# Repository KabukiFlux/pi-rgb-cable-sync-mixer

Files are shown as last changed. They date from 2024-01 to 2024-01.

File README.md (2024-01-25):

# RGBpi cable sync mixer

Small PCB mod to mix the sync in the RGBpi cable to solve sync issues

## Table of contents

- [Why](#why)
- [Description](#description)
- [Schematics](#schematics)
- [Install](#install)
- [Pics and final result](#pics-and-final-result)

## Why?

In order to eliminate/mitigate the sync issues on the cable we can do several options,
one is to use the common XOR mixer as usual, this other approach reduces the BOM
and enables the PCB to fit in the scart cable connector without any problem.

As you can see on this screenshot the original cable without modding induces a lot of 
DC bias on the sync causing some issues on some TVs, arcade monitors and so: 

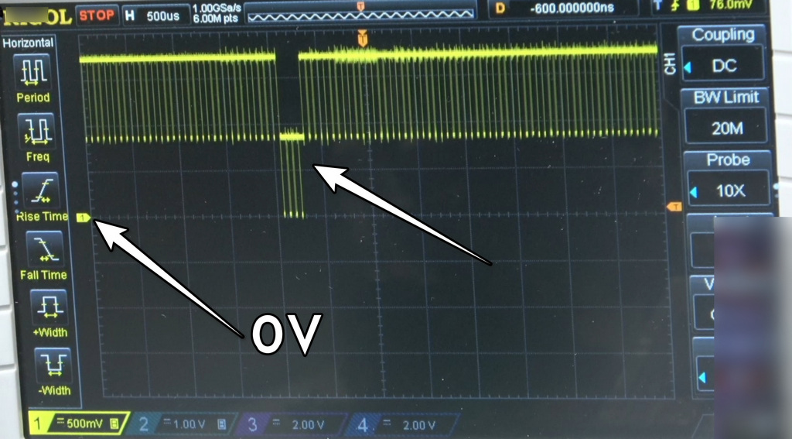
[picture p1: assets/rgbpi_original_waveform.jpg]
RGBpi original cable waveform


With this mod we remove the DC offset not mixing into a full CSync signal but at least
we enable it to be used on more systems, of course the best approach is always the active sync
mixer with some gates but with this mod we restore at least the basic functionality.

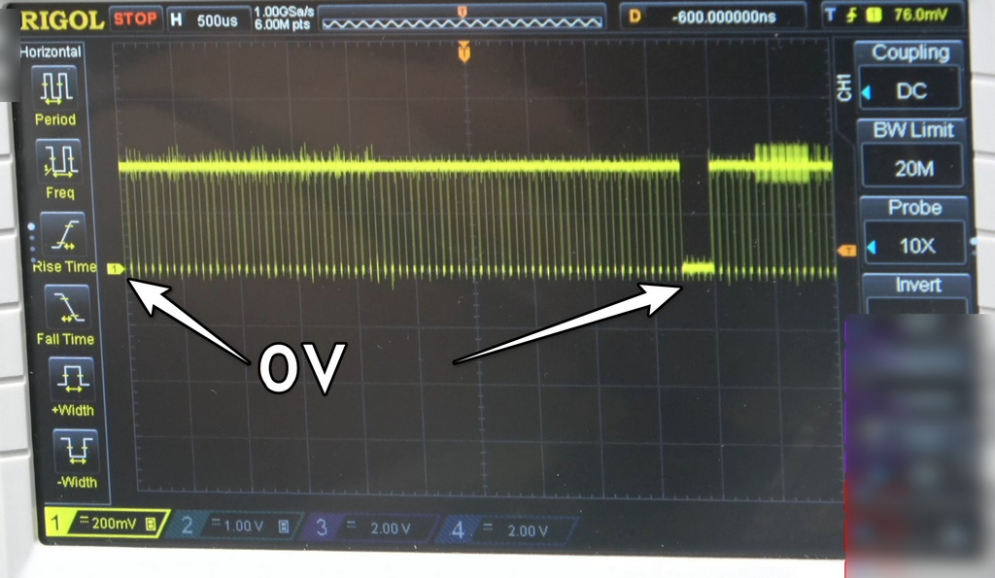
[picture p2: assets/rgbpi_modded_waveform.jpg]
RGBpi modded cable waveform


Yes, the vertical period is not as good as with an active mixer but at least it removes the sync
issues on most devices with a very small BOM.

### OSSC comparison

Without modding:

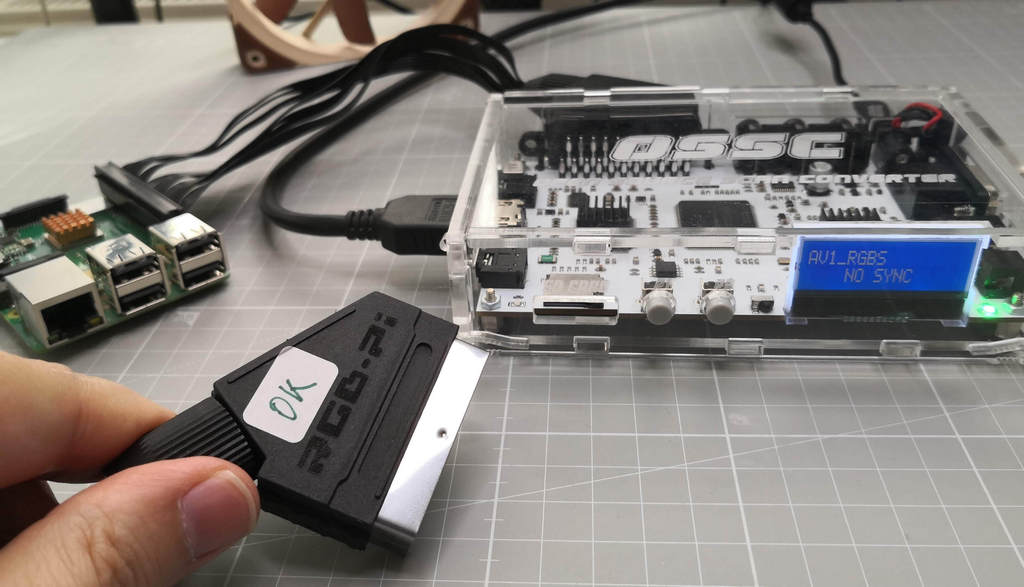
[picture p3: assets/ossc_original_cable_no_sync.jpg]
OSSC without modding


Modded cable:

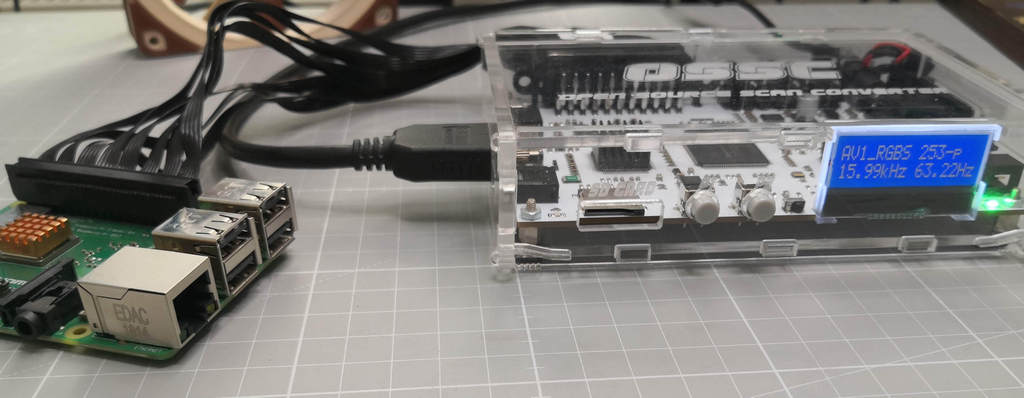
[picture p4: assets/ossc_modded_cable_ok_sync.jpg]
OSSC modded cable


## Description

This is intended to be a very small PCB to be included inside the scart connector on the rgbpi cable.

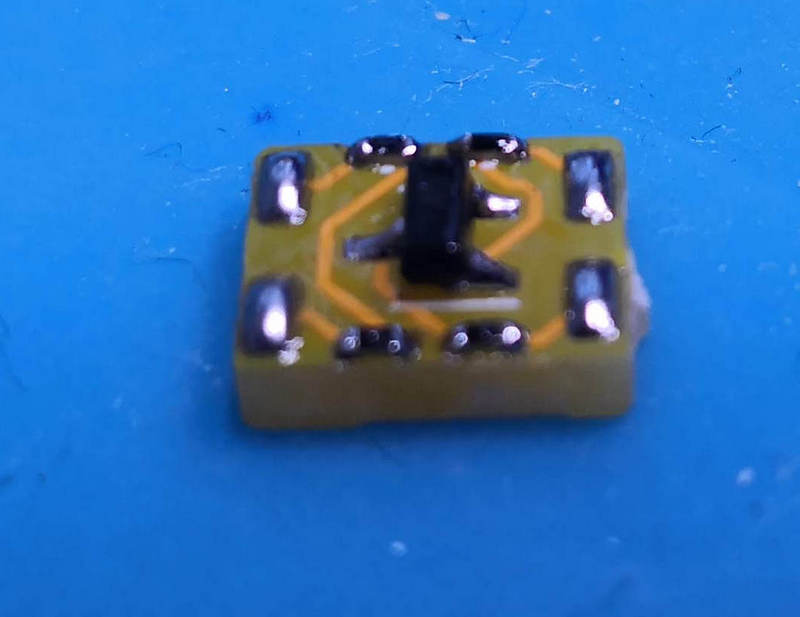
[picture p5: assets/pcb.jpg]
Sync mixer PCB


It is valid for all the rgbpi cable versions, we will see on the installation procedure V1 and V2 cables.

In the BOM directory there's an interactive BOM with all the required components.

In the gerbers directory we have the gerbers to manufacture the boards.

In the KiCAD folder we can find the KiCAD project itself.

## Schematics

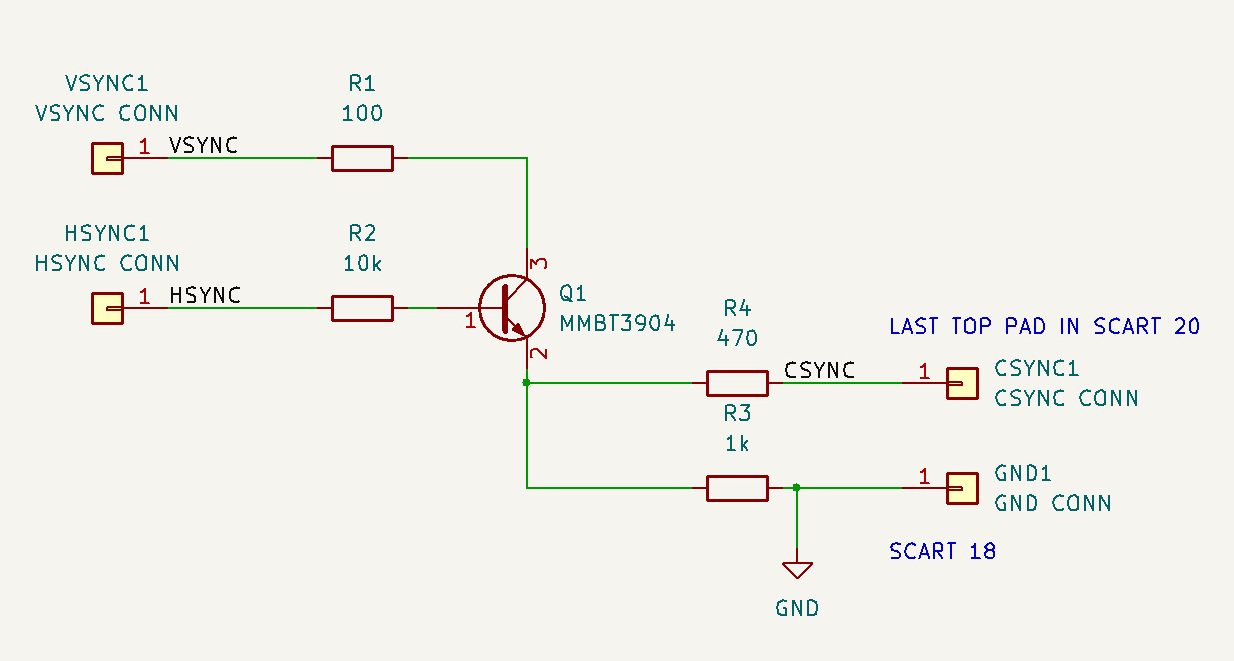
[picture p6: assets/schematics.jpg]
Schematics


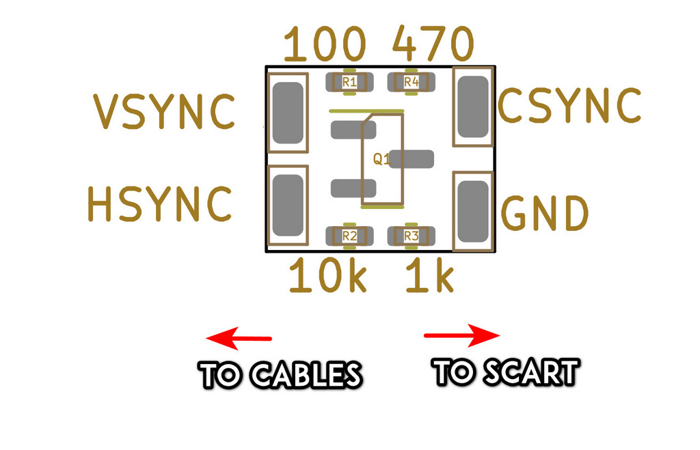
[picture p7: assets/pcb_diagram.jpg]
PCB footprint


You can find here as well as the KiCAD files inside the KiCAD folder.

## Install

1- Send to manufacture the GERBER board to JLCPCB or other PCB manufacturer.

2- Get the components required, you can see here the Bill Of Materials [BOM](bom/ibom.html)

3- Solder the components.

4- Follow the procedure depending on your cable version.

### Detect your cable version

This is what we will call V1, follow the V1 install procedure:

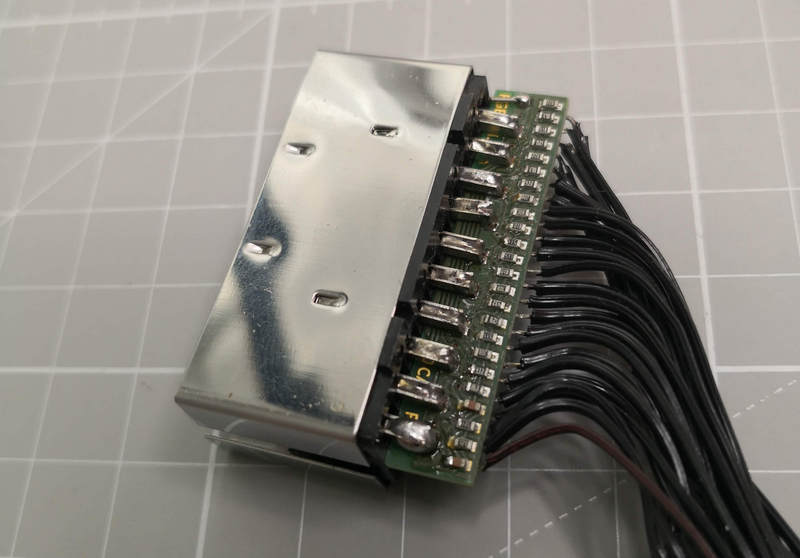
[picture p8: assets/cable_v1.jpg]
Cable V1


This is what we will call V2, follow the V2 install procedure:

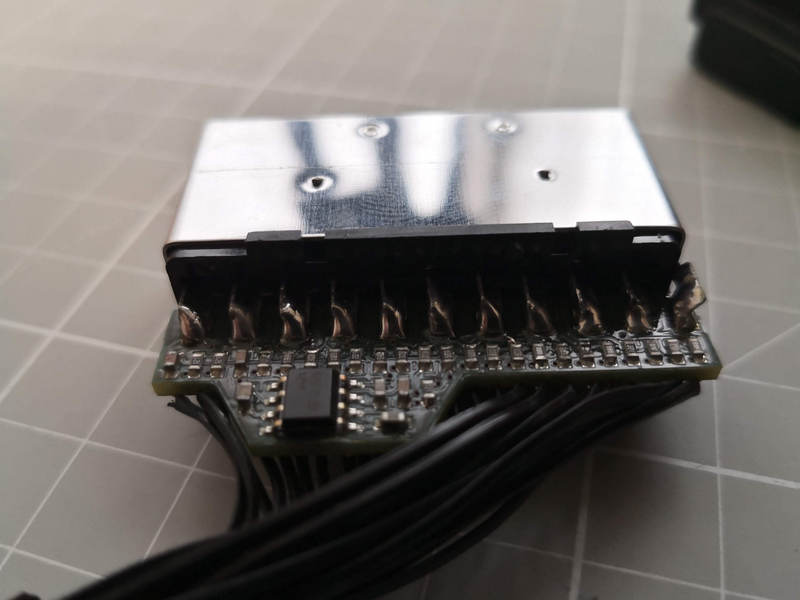
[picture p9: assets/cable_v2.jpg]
Cable V2


### V1 cable install

If your cable is V1 then:

* Check the wires for the installation

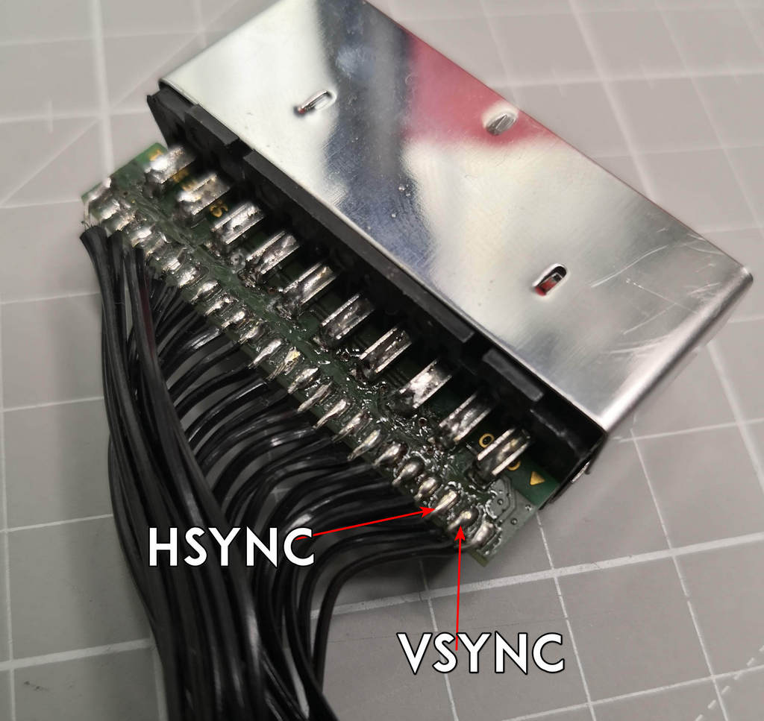
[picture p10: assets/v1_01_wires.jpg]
v1 wires


* Check the soldering positions

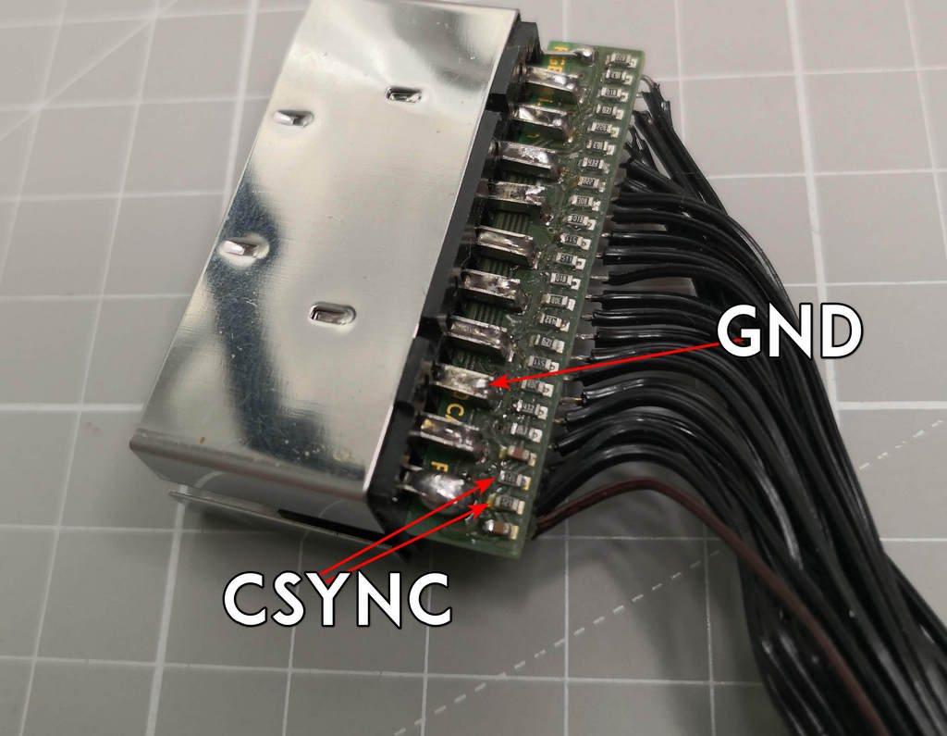
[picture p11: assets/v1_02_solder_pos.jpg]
v1 soldering positions


* Solder as shown (the big white cable is not required by this mod)

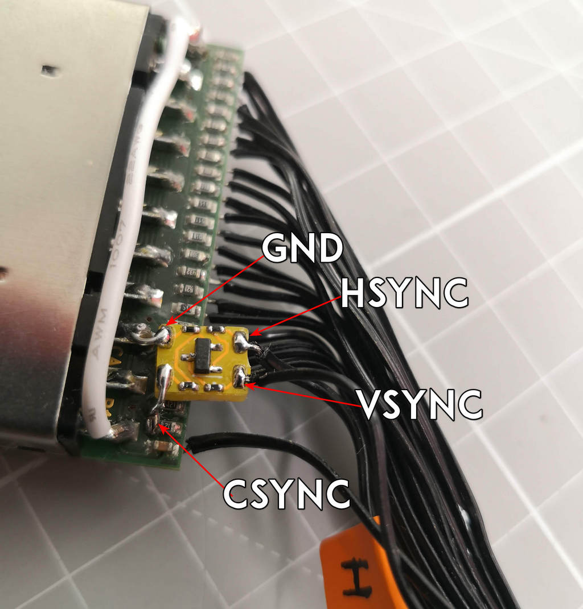
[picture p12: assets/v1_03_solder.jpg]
v1 solder


### V2 cable install

If your cable is V2 then:

* Check the wires for the installation

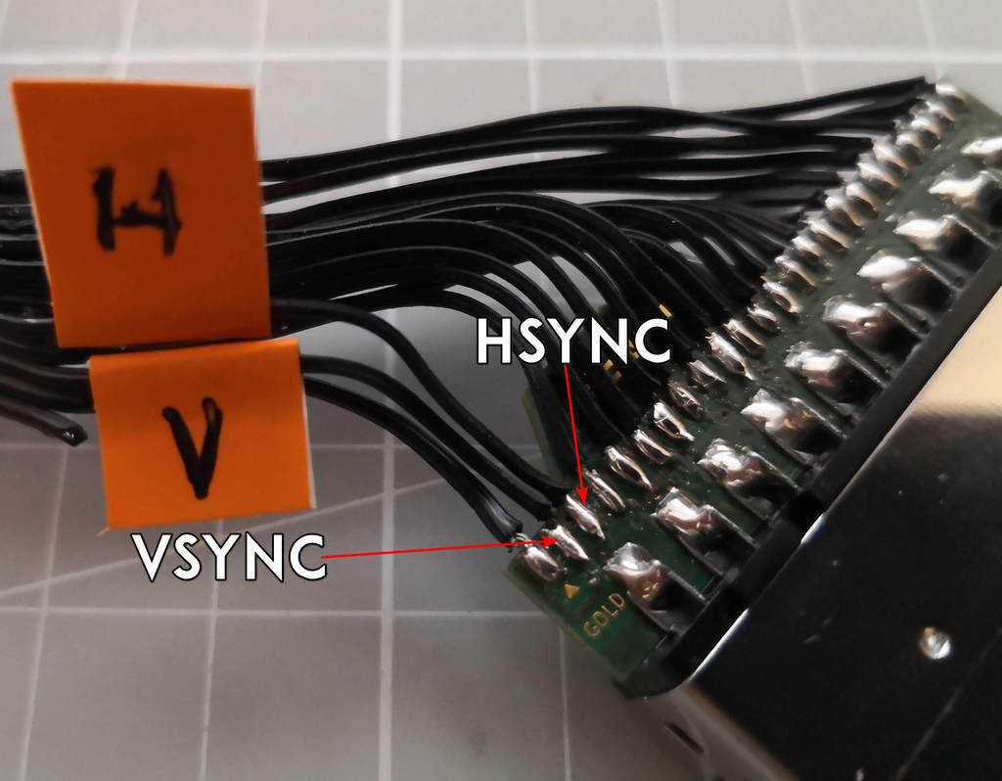
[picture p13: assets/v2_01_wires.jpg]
v2 wires


* Check the soldering positions

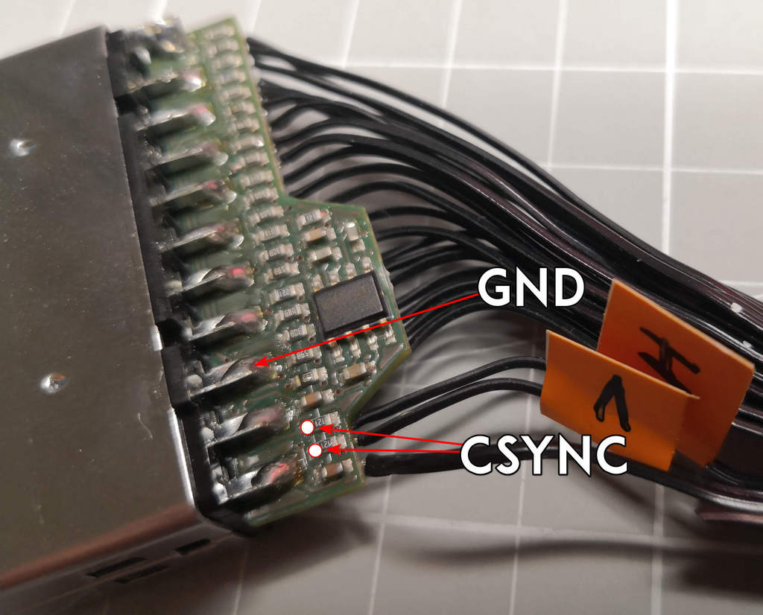
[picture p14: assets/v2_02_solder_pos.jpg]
v2 soldering positions


* Place as shown

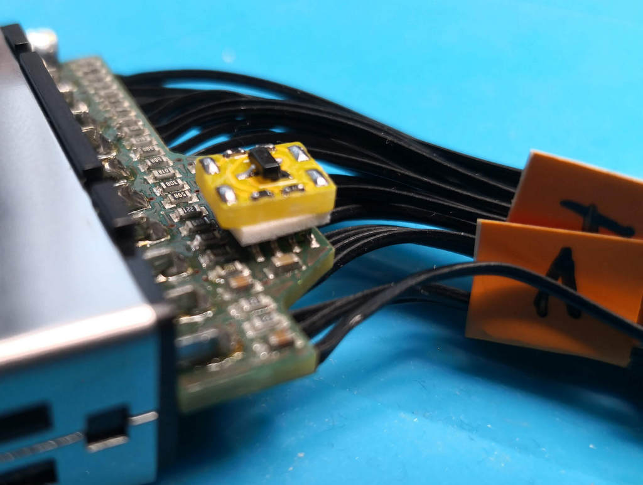
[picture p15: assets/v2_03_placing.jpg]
v2 placing


* Solder the scart part (you can use for GND the 3rd pin from the bottom, it is better)

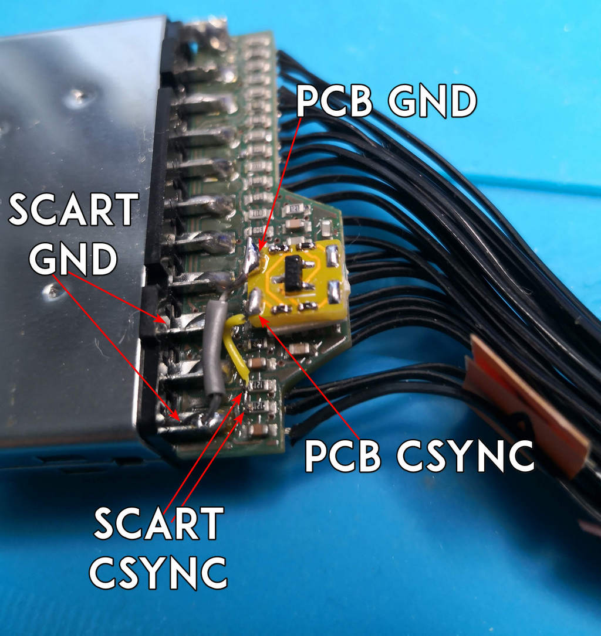
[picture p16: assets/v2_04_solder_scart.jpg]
v2 solder scart part


* Solder the cable hsync and vsync wires

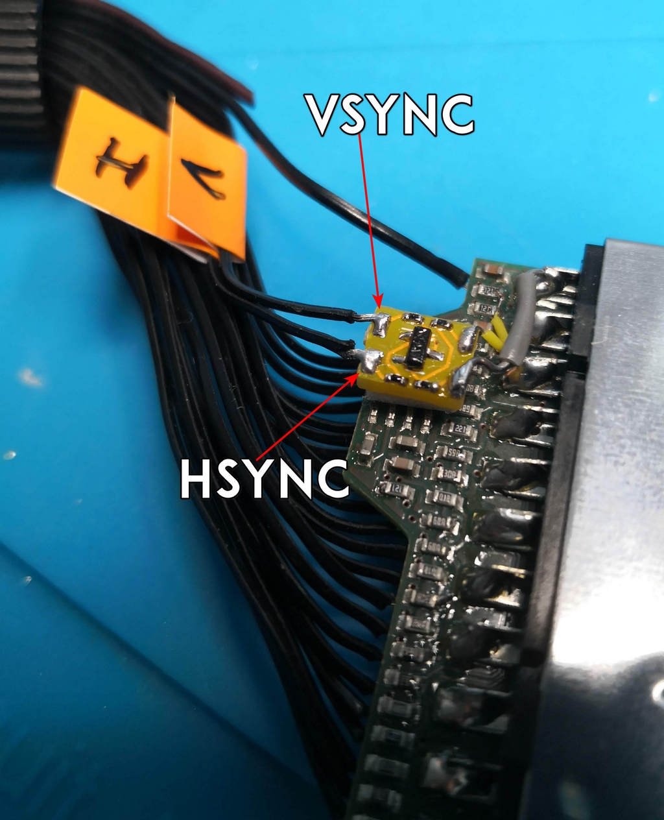
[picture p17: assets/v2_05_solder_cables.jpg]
v2 solder sync wires


### Pics and final result

V1:

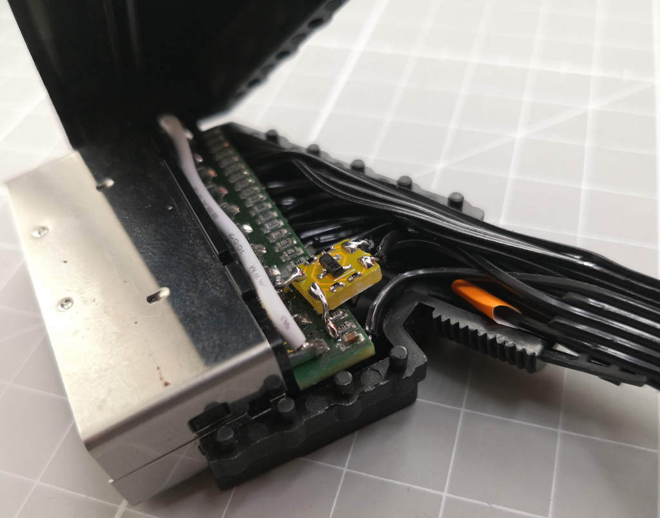
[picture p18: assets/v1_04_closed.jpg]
V1 close


V2

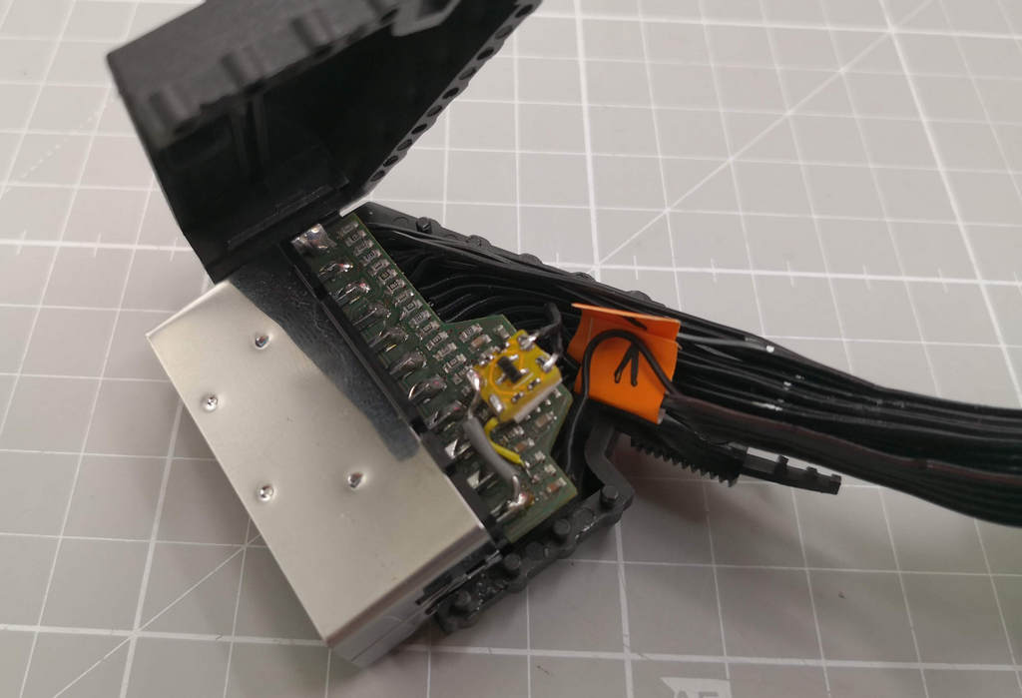
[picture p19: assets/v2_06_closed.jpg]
V2 close


That's it.

I'm not responsible
============
And yes, read below, no responsibility taken on bad use.

Special thanks to Retroark [here on X](https://twitter.com/retroark) 

DISCLAIMER (See Licensing)
==========================
See LICENSE fo more information.

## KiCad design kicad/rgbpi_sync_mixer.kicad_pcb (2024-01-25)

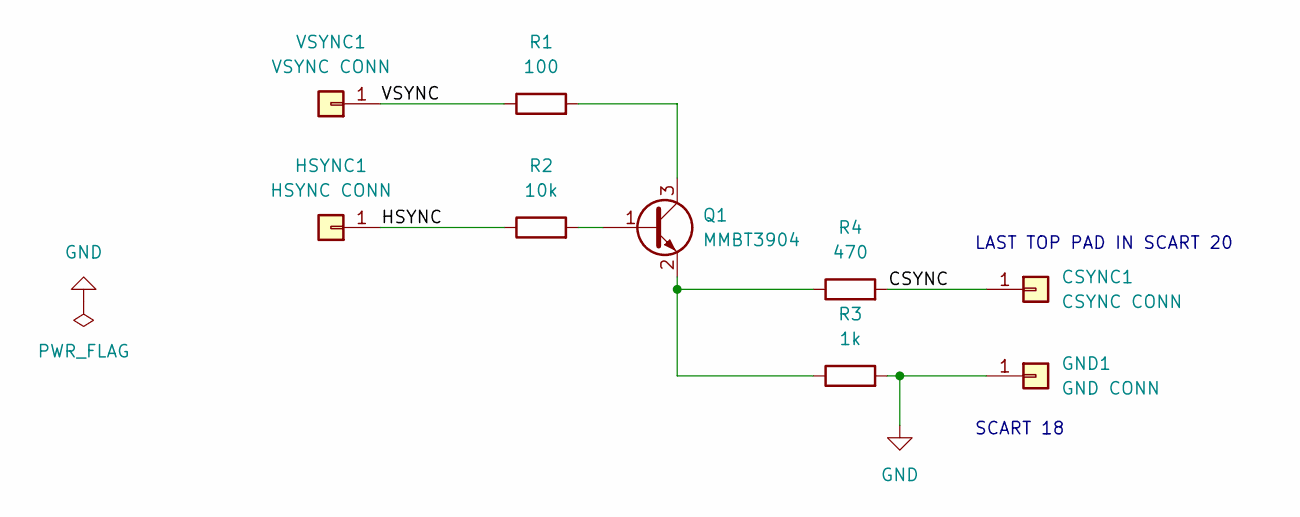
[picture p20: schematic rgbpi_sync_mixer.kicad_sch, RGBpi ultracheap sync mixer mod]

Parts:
CSYNC1: CSYNC CONN; SolderWirePad_1x01_SMD_1x2mm
GND1: GND CONN; SolderWirePad_1x01_SMD_1x2mm
HSYNC1: HSYNC CONN; SolderWirePad_1x01_SMD_1x2mm
Q1: MMBT3904; SOT-23
R1: 100; R_0402_1005Metric
R2: 10k; R_0402_1005Metric
R3: 1k; R_0402_1005Metric
R4: 470; R_0402_1005Metric
VSYNC1: VSYNC CONN; SolderWirePad_1x01_SMD_1x2mm

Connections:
/CSYNC: CSYNC1.1, R4.2
/HSYNC: HSYNC1.1, R2.1
/VSYNC: R1.1, VSYNC1.1
GND: GND1.1, R3.2
unnamed: Q1.1 (B), R2.2
unnamed: Q1.3 (C), R1.2
unnamed: Q1.2 (E), R3.1, R4.1

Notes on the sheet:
LAST TOP PAD IN SCART 20
SCART 18

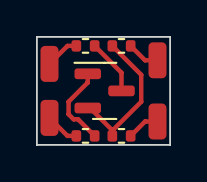
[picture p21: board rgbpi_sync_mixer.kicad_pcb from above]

Board: 2 copper layers, 7.4 x 6.0 mm, 9 parts (0 on the bottom side), 7 nets.
